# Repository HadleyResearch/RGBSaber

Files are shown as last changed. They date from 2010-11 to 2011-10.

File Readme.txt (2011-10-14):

File: README.txt
Description: Project-specific instructions and information concerning files
    located within this hierarchy and subhierarchies. In the event of
    conflicts, the lowest-level README.txt file is used for information
    regarding a file or files.

Current Location: RGBSaber/

Description:
    The RGBSaber project is an open-source electronics system for professional
lightsaber replicas. The RGBSaber electronics consist of a single channel high
power RGB LED control interface, allowing the user to implement full digital
color control over the color of the lightsaber blade.

Contents:
    Included in this repository are the source files and documentation
necessary to recreate RGBSaber. If you believe something is missing
from the project, please contact us at http://nbitwonder.com/blog/contact

Documentation:
    Documentation related to this project is included in the 'Documentation'
folder. For additional documentation and other information, please see:
    http://nbitwonder.com/blog/projects/rgbsaber

License Information:
    NBitWonder projects are released under the GNU GPL v3.0 for software,
firmware, simulations, and documentation and Creative Commons CC-BY-3.0 
for electronics and mechanical components. License copies can be found in the
file 'license.txt' in each of these top-level folders.
    NBitWonder projects may use files, software, libraries, etc. which is not
open source. These components may not be distributed within the project
repository or use a different license than that specified in license.txt. In
these cases, acquisition instructions and license exceptions are noted in a
given hierarchy's 'README.txt' file. Where conflicting, the lowest-level
'README.txt' file shall apply to a given file or files.

George Hadley
Chief Executive Officer
NBitWonder, LLC

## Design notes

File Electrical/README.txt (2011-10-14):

File: README.txt
Description: Project-specific instructions and information concerning files
    located within this hierarchy and subhierarchies. In the event of
    conflicts, the lowest-level README.txt file is used for information
    regarding a file or files.

Current Location: RGBSaber/Electrical

Components:
    The following RGBSaber components exist in this directory:
    + RGBSaber_Control: The main control board for the RGBSaber project, contains
            the microcontroller and performs all of the device functionality
    + RGBSaber_Periph1: Peripheral board for interface to RGBSaber_Control. Uses
            a sliding potentiometer, actively developed.
    + RGBSaber_Periph2: Peripheral board for interface to RGBSaber_Control. Uses
            a rotary potentiometer, not recommended.
    + Tricolor: DEPRECATED. Original version of the board containing instances of
            both the control and peripheral boards. Do not build.

Software:
    All electronic design files were created using EagleCAD v5.11 from CADSoft. 
A freeware copy of this software, as well as additional information about this 
software, can be found at http://www.cadsoftusa.com/

License:
    All electronic CAD design files contained within this hierarchy, except those
noted in the 'Exceptions' section below, are made publicly available via a 
Creative-Commons CC-BY-SA 3.0 license. For more information on the license, see 
http://creativecommons.org/licenses/by-sa/3.0/
    Additionally, a complete copy of the license text can be found in the file
'license.txt' distributed within this folder.

Exceptions:
    The following alternative licensing requirements apply to the following files:

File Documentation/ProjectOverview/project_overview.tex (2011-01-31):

% File: project_overview.tex
% Description: TeX file to generate project overview template
% Author: George Hadley
% Website: http://nbitwonder.com
% Notes:
% 1) This document is written using the LaTeX typesetting language. For a beginner's
%	guide to the LaTeX typesetting language, consult http://en.wikibooks.org/wiki/LaTeX
% 2) This document needs to be compiled using pdfLaTeX. It is not compatible with pdfTeX 
%	at the present time.
% 3) This document utilizes the nbwheader function, located in the doc_header.tex file.
%	This file is located at /path-to-documentation-templates/lbr/doc_header.tex.
% Version: 0.1
% Last Modified: 1-04-2010

\documentclass[12pt,letterpaper,onecolumn]{article}
\usepackage{graphicx}
\usepackage{float}
\usepackage{subfig}
\usepackage{tikz}
\usepackage{fancyhdr}
\usepackage{verbatim}
\usepackage{kpfonts}
\usepackage{fullpage}
\usepackage{hyperref}

%Pathway to global documentation library functions
%Modify to /path-to-documentation-templates/lbr
\newcommand{\globallbr}{../lbr}

%Page layout settings
\setlength{\voffset}{-10pt}
\setlength{\headsep}{20pt}
\setlength{\headheight}{15pt}
\setlength{\topmargin}{-20pt}

\begin{comment}
  Hyperref settings: settings for the hyperref hyperlink package.
  For a more detailed listing of available settings, consult 
  	http://en.wikibooks.org/wiki/LaTeX/Hyperlinks#Customization

  IMPORTANT: For your document, modify the pdftitle, pdfauthor, pdfsubject,
	and pdfkeywords options to tailor to your document
\end{comment}
\hypersetup{
	bookmarks=true, 					%Enable pdf bookmarks
	pdfborder={0,0,0},					%Disable borders around links
	pdftitle={Project Overview (template)},		%Name of PDF document
	pdfauthor={George Hadley},				%Author of PDF document
	pdfsubject={Embedded Electronics},		%Subject of PDF document
	pdfkeywords={diy,electronics,nbitwonder},	%Keywords for PDF document
	colorlinks={true},					%Enable colored links
	linkcolor=red,						%Internal link color
	citecolor=green,						%Citation link color
	filecolor=blue,						%File link color
	urlcolor=blue						%URL link color
}

\input{\globallbr/doc_header.tex}
\input{\globallbr/aliases.tex}

%Modify these to reflect your documentation
\newcommand{\documentationtype}{Project Overview}
\newcommand{\projectname}{RGBSaber }
\newcommand{\projectversion}{1}

%Header/Footer Definitions
\pagestyle{fancy}
\lhead{ }
\chead{ }
\rhead{\projectname  v\projectversion \documentationtype}
\lfoot{\href{http://nbitwonder.com}{http://nbitwonder.com} }
\cfoot{\thepage}
\rfoot{\copyright 2011 NBitWonder, LLC }

\begin{document}
\thispagestyle{plain}
% Insert title page or header here
\nbwheader{\documentationtype}{\projectname}{\projectversion}

%Uncomment to add Table of Contents to Project Overview
\tableofcontents
\newpage

\section[Project Description]{Project Description}
% Section: Project Description
% Description: A brief description of what your project is and what it will be used for
The RGBSaber is an open source RGB Luxeon LED driver. The driver allows for PWM modulation of an RGB
luxeon LED, allowing the color of the lightsaber blade to be adjusted to nearly any color in the RGB color spectrum. The current version of the lightsaber firmware supports 24-bit color, allowing for 16,777,216 different color combinations. The RGBSaber project, and all other NBitWonder projects, are made available under a \href{http://creativecommons.org/licenses/by-sa/3.0/}{Creative Commons 3.0 BY-SA license}.

\section[Schematics]{Schematics and Block Diagrams}
% Section: Schematics and Block Diagrams
% Description: Include any relevant high level schematics and block diagrams in this section

\section[Project Roadmap]{Project Roadmap}
% Section: Project Roadmap
% Description: Detail improvements and upgrades to be considered for future versions 
%	of the project
The RGBSaber system has considerable upgrade potential over the course of the project. A rough
project roadmap looks something like this:

\underline{\textbf{Control Board}}
\begin{enumerate}
\item\textbf{Version 1:} Basic RGBSaber system, capable of full RGB color control.
\item\textbf{Version 2:} Modular system, featuring hardware plugins for sound. Integration of
	sound with RGB color control
\item\textbf{Version 3:} Upgraded lightsaber transistor drive capabilities.
\end{enumerate}

\textbf{\underline{Peripheral Board}}
\begin{enumerate}
\item\textbf{Version 1:} Simple functional peripheral board.
\item\textbf{Version 2:} Improved peripheral board with touch interface
\end{enumerate}

\section[Project Analysis]{Project Analysis}
% Section: Project Analysis
% Description: Analysis of project compared to similar/competing projects, products, 
%	and patents. Divided into subsections (below)

\subsection[Open Source]{Open Source Project Analysis}
% Subsection: Open Source Analysis
% Description: Analysis of project compared to similar open source projects.
To date, no other known open source RGB lightsaber systems appear to exist. That said, there are a number 
of boards online that are designed to do RGB color mixing.

\subsubsection[Dangerous Prototypes]{Dangerous Prototypes USB RGB Color Changer}
Dangerous Prototypes produced a \href{http://dangerousprototypes.com/2010/01/21/usb-rgb-color-changer-build/}{USB RGB color changer} some time ago. This design was only ever in the prototype stage,
and is not in production. Additionally, the boards are far too large to fit into a lightsaber form factor and
use through-hole parts. As such, this design is not seen as a strong competitor to the RGB Lightsaber
design.

\subsubsection[Macetech]{MaceTech ShiftBrite Project}
Open source company Macetech developed and manufactures an RGB color mixing system known as the
\href{http://macetech.com/blog/?q=node/23}{ShiftBrite}. The ShiftBrite RGB system is theoretically small
enough to fit inside of a lightsaber hilt environment. However, the LEDs and the driving circuitry for the
ShiftBrite system are not bright and powerful enough to see use in a lightsaber system.

\subsection[Commercial]{Commercial Product Analysis}
% Subsection: Commercial Product Analysis
% Description: Analysis of project compared to similar commercial products
\subsubsection[Sparkfun]{Sparkfun Electronics RGB Triple Play}
In late 2010, Sparkfun electronics released the \href{http://www.sparkfun.com/products/9738}{RGB Triple Play} and an associated \href{http://www.sparkfun.com/products/9834}{driver}.
Coupled with a triple LED lens, these products certainly hit closer to the RGBSaber system. However, at the
time of this writing, these products are still too bulky to be used in a lightsaber environment, and also vastly
overpriced (costing approximately 70 dollars for the LED and drivers alone, without any control electronics).
As such, Sparkfun's products are not seen as a particular threat to the RGBSaber project.

\subsection[Plecter Labs]{Plecter Labs Crystal Focus System}
Lightsaber company Plecter Labs produces a lightsaber core system known as \href{http://www.plecterlabs.com/catalog/product_info.php?cPath=23&products_id=149}{Crystal Focus}
which is an extremely strong competitor to the RGBSaber project. The board is extremely high end, and 
features many advanced features, particularly sound and swing/clash detection.  The board is not capable
of RGB color control at the present time, and only supports a single channel. Nonetheless, the system
could be modified to support RGB color without too much effort. The system is decidedly a high-end
system at the present time (costing approximately 200 USD per board), so a slightly less featured but
cheaper board could be a prominent competitor to this system.

\subsection[Patent]{Patent Analysis}
% Subsection: Patent Analysis
% Description: Analysis of project compared to existing patents
At the present time, the RGBSaber project uses simple PWM color mixing techniques. These techniques are
trivial and well documented in the public domain, and, as such, patent analysis and infringment is not
anticipated or likely.

\section[Sources Cited]{Sources Cited}
% Section: Sources Cited
% Description: Citations for all sources used within the document.
%	Use of the IEEE citation style is highly recommended. For guidelines on using the IEEE citation style, 
%	refer to:
%	http://www.ieee.org/portal/cms_docs_iportals/iportals/publications/authors/transjnl/stylemanual.pdf

\end{document}

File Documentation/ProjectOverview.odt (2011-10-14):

Project Overview

Project: RGBSaber

Date: 10-13-2011

# 1.0. Project Description

RGBSaber is an open-source, single-channel high power LED driver. The device is capable of implementing complete digital color control on a single high-intensity LED via pulse width modulation (PWM). In this way, the color of a lightsaber blade can be changed to any color in the RGB color spectrum.

# 2.0. Project Roadmap

The following versions are considered for the RGBSaber project:

RGBSaber_Control:

- Version 1: Basic digital color control, user saveable/selectable colors, sleep mode
- Version 2: Improved connectors, modular daughterboard system, SOUND, integrated accelerometer
- Version 3: User programmability, configurable peripheral interface

RGBSaber_Periph:

- Version 1: Basic user interface
- Version 2: Capacitive touch interface

Sound Driver (supported with RGBSaber_Control v2.0 and later):

- Version 1: Basic operational model
- Version 2: Support for sound fonts, microSD card support

Transistor Driver Boards:

- 3W RGB Transistor driver
- 5W WRGB Transistor driver
- 10W WRGB Transistor driver

RGBSaber_Chassis:

- Version 1.0: Basic operational model

# 3.0. Legal Analysis

## 3.1. Regulatory Analysis and Compliance

As with other active NBitWonder projects at the time of this writing, RGBSaber has no useful defense or medical applications, does not emit appreciable radiation at any radio frequencies, and is incapable of flight. Therefore, ITAR, medical device, FCC, and FAA regulatory compliance is assumed, and regulatory issues are not expected.

## 3.2. Patent Analysis

At the time of this writing, RGBSaber utilizes extremely simple PWM color mixing techniques. These techniques are trivial and well documented in the public domain, so patent infringement and related issues are not expected.

# 4.0. Competitor Analysis

## 4.1. Open Source Project Analysis

At the time of this writing, no other known open source RGB lightsaber systems are known to exist. That said, there are a few noteworthy open source projects capable of doing RGB color mixing.

### 4.1.1. Dangerous Prototypes USB RGB Color Changer

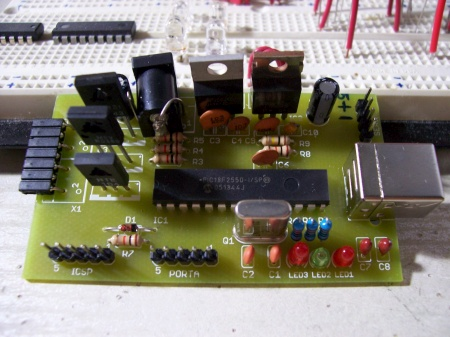
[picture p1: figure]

Fig. 1. Dangerous Prototypes USB Color Changer

Dangerous Prototypes produced a USB RGB color changer (http://dangerousprototypes.com/2010/01/21/usb-rgb-color-changer-build/) some time ago. This design was only ever in the prototype stage, was never produced, and is no longer actively developed. Additionally, the boardsare far too large to fit into a lightsaber form factor and use through-hole parts. As such, this design is not seen as a strong competitor to the RGB Lightsaber design.

### 4.1.2. MaceTech ShiftBrite Project

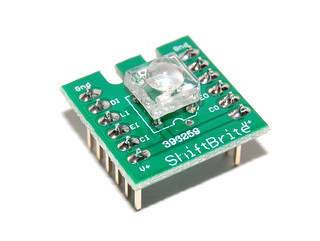
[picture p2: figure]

Fig. 2. MaceTech ShiftBrite Module

Open source company MaceTech developed and manufactures an RGB color mixing system known as the ShiftBrite (http://macetech.com/blog/?q=node/23). The ShiftBrite RGB system is theoretically small enough to fit inside of a lightsaber hilt environment. However, the LEDs and associated driving circuitry for the ShiftBrite system are not bright and powerful enough to see use in a practical lightsaber system, and no focusing optics for narrowing the ShiftBrite beam to an acceptably narrow width are known to exist.

## 4.2. Commercial Product Analysis

### 4.2.1. Sparkfun Electronics RGB Triple Play

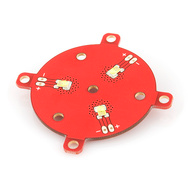
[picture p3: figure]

Fig. 3. Sparkfun RGB Triple Play

In late 2010, Sparkfun Electronics released the RGB Triple Play (http://www.sparkfun.com/products/9738) and associated drive circuitry. Coupled with a tri-LED optical lens, these products certainly hit closer to the RGBSaber system than most competitors. However, at the time of this writing, these products are still too bulky to see effective use inside of a lightsaber hilt, and are also vastly overpriced (costing approximately 70 dollars for the LED and drivers alone, without any control electronics). As such, Sparkfun's products are not seen as strong competitors to the RGBSaber project.

### 4.2.2. Plecter Labs Crystal Focus System

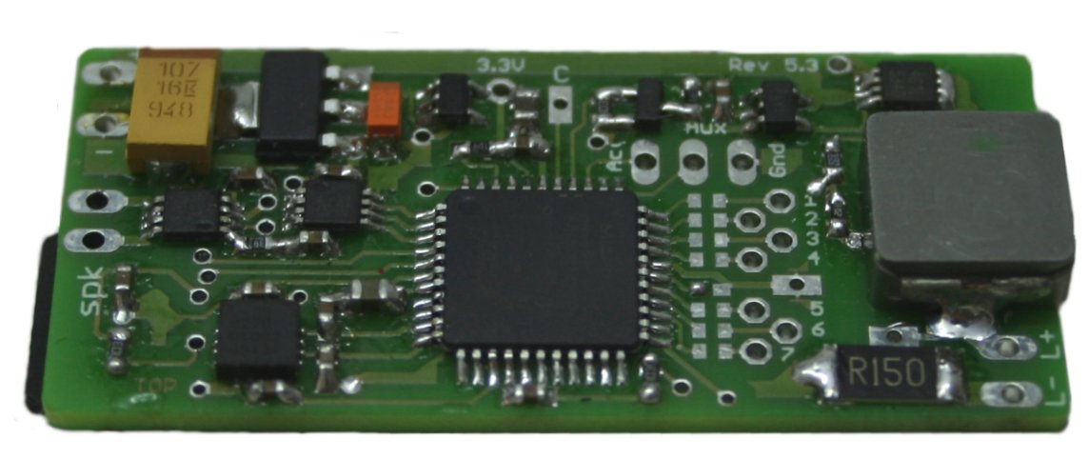
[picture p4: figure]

Fig. 4. Plecter Labs Crystal Focus System

Lightsaber company Plecter Labs produces a set of lightsaber electronics known as Crystal Focus (http://www.plecterlabs.com/catalog/product_info.php?cPath=23&products_id=149), which is seen as the primary competitor to the RGBSaber project. The board is the most advanced set of lightsaber electronics known, and includes many advanced features, such as sound and swing/clash detection. The board is not capable of RGB color control at the present time, and only supports a single channel. Nonetheless, the system could be modified to support RGB color without too much effort. The system is decidedly a high-end system at the present time (costing approximately USD 200 per board), so a slightly less featured but cheaper board could be a prominent competitor to this system.

RGBSaber Project Overview

http://nbitwonder.com 3 © 2011 NBitWonder, LLC

http://nbitwonder.com 3 ©2011 NBitWonder LLC

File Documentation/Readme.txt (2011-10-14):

File: README.txt
Description: Project-specific instructions and information concerning files
    located within this hierarchy and subhierarchies. In the event of
    conflicts, the lowest-level README.txt file is used for information
    regarding a file or files.
            
Current Location: RGBSaber/Documentation

    NBitWonder's open documentation system follows the guidelines written 
in our documentation tutorial, which can be found at:
	 http://nbitwonder.com/2010/11/09/becoming-a-better-maker-documentation/

Documents included are:
	1)  Project Overview
	2)  Project Notebook
	3)  Theory of Operation
	4)  Bill of Materials (BOM)
	5)  Construction Guide
	6)  User Manual
    
License:
	All macros and documentation templates are provided under the GNU GPL 
v3.0. A full copy of the GNU GPL v3.0 can be found at: 
    http://www.gnu.org/copyleft/gpl.html
    Additionally, a copy of the GNU GPL v3.0 should be included in the file
license.txt.
	All documentation produced by NBitWonder is the copyright of NBitWonder.
In addition, NBitWonder and the NBitWonder logo are trademarks of NBitWonder
and their use is strictly prohibited except by express written permission 
from NBitWonder, LLC.

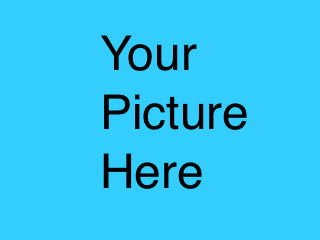
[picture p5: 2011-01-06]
Documentation/ProjectOverview/img/sample_picture.png

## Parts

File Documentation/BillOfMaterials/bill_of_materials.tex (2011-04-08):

% File: bill_of_materials.tex
% Description: TeX file to generate Bill of Materials (template)
% Author: George Hadley
% Notes:
% 1) This document is written using the LaTeX typesetting language. For a beginner's
%	guide to the LaTeX typesetting language, consult http://en.wikibooks.org/wiki/LaTeX
% 2) This document needs to be compiled using pdfLaTeX. It is not compatible with pdfTeX 
%	at the present time.
% 3) This document utilizes the nbwheader function, located in the doc_header.tex file.
%	This file is located at /path-to-documentation-templates/lbr/doc_header.tex
% Version: 0.1
% Last Modified: 1-04-2010
\documentclass[12pt,letterpaper,onecolumn,landscape]{article}
\usepackage{tikz}
\usepackage{verbatim}
\usepackage{kpfonts}
\usepackage[cm]{fullpage}
\usepackage{hyperref}

%Location of global library functions
%Change to /path-to-templates/br
\newcommand{\globallbr}{../lbr}

\begin{comment}
  Hyperref settings: settings for the hyperref hyperlink package.
  For a more detailed listing of available settings, consult 
  	http://en.wikibooks.org/wiki/LaTeX/Hyperlinks#Customization

  IMPORTANT: For your document, modify the pdftitle, pdfauthor, pdfsubject,
	and pdfkeywords options to tailor to your document
\end{comment}
\hypersetup{
	bookmarks=true, 					%Enable pdf bookmarks
	pdfborder={0,0,0},					%Disable borders around links
	pdftitle={Bill of Materials: RGBSaber v1.5},	%Name of PDF document
	pdfauthor={George Hadley},				%Author of PDF document
	pdfsubject={Documentation},			%Subject of PDF document
	pdfkeywords={diy,electronics,nbitwonder},	%Keywords for PDF document
	colorlinks={true},					%Enable colored links
	linkcolor=red,						%Internal link color
	citecolor=green,						%Citation link color
	filecolor=blue,						%File link color
	urlcolor=blue						%URL link color
}

\input{\globallbr/doc_header.tex}
\input{\globallbr/aliases.tex}

\begin{document}
	\nbwheader{Bill of Materials}{RGBSaber}{1.5}
	\\*
	\\*
	\\*
	%Include data for the components of your project. Recommended fields include description, quantity,
	%  value, package, manufacturer, mfg part #, supplier, supplier part #

	%Adjust the tab values (l/c/r = left/right/center justified, p{xcm} = constrain width to x cm (x integer)
	\noindent
	\begin{tabular}{ | p{4cm} | c | l | p{3cm} | p{4cm} | l | l | p{4cm} |}
	\hline
	\multicolumn{8}{| l |}{\textbf{RGBSaber\_Control}} \\ \hline
	\textbf{Description} & \textbf{Qty} & \textbf{Value} & \textbf{Package} & \textbf{Manufacturer} & \textbf{Manufacturer Part \#} & \textbf{Supplier} & \textbf{Supplier Part \#} \\ \hline
	%Description
	Microcontroller &
	%Quantity
	1 & 				
	%Value
	 & 		
	%Package	
	SSOP-28 & 		
	%Manufacturer
	\href{http://microchip.com}{Microchip} & 		
	%Manufacturer Part #
	\href{http://www.microchip.com/wwwproducts/Devices.aspx?dDocName=en024612}{PIC18F2221-I/SS} & 
	%Supplier
	\href{http://digikey.com}{DigiKey} &
	%Supplier Part # 
	\href{http://search.digikey.com/scripts/DkSearch/dksus.dll?Detail\&name=PIC18F2221-I/SS-ND}{PIC18F2221-I/SS-ND}
	\\ \hline
	
	%Description
	DC/DC Converter &
	%Quantity
	1 & 				
	%Value
	 & 		
	%Package	
	Through Hole & 		
	%Manufacturer
	\href{http://www.murata-ps.com/}{Murata Power Solutions} & 		
	%Manufacturer Part #
	\href{http://www.murata-ps.com/data/power/okr-t3-w12.pdf}{OKR-T/3-W12-C} & 
	%Supplier
	\href{http://digikey.com}{DigiKey} &
	%Supplier Part # 
	\href{http://search.digikey.com/scripts/DkSearch/dksus.dll?WT.z_header=search_go\&lang=en\&site=us\&keywords=okr-t\%2F3-w12\&x=0\&y=0}{811-2115-5-ND}
	\\ \hline

	%Description
	Switching Transistor &
	%Quantity
	3 & 				
	%Value
	 & 		
	%Package	
	SOT-223 & 		
	%Manufacturer
	\href{http://www.diodes.com/index.php}{Zetex Semiconductor} & 		
	%Manufacturer Part #
	\href{http://www.diodes.com/datasheets/FZTA14.pdf}{FZTA14TA} & 
	%Supplier
	\href{http://digikey.com}{DigiKey} &
	%Supplier Part # 
	\href{http://search.digikey.com/scripts/DkSearch/dksus.dll?Detail\&name=FZTA14CT-ND}{FZTA14CT-ND}
	\\ \hline

	%Description
	Feedback Resistor &
	%Quantity
	1 & 				
	%Value
	250\ohm & 		
	%Package	
	0805 & 		
	%Manufacturer
	 & 		
	%Manufacturer Part #
	 & 
	%Supplier
	 &
	%Supplier Part # 
	
	\\ \hline

	%Description
	Red BJT Base Resistor &
	%Quantity
	1 & 				
	%Value
	6.67k\ohm & 		
	%Package	
	0805 & 		
	%Manufacturer
	 & 		
	%Manufacturer Part #
	 & 
	%Supplier
	 &
	%Supplier Part # 
	
	\\ \hline

	%Description
	Green/Blue BJT Base Resistor &
	%Quantity
	2 & 				
	%Value
	3.3k\ohm & 		
	%Package	
	0805 & 		
	%Manufacturer
	 & 		
	%Manufacturer Part #
	 & 
	%Supplier
	 &
	%Supplier Part # 
	
	\\ \hline
	
	%Description
	Pull-up Resistor &
	%Quantity
	2 & 				
	%Value
	10k\ohm & 		
	%Package	
	0805 & 		
	%Manufacturer
	 & 		
	%Manufacturer Part #
	 & 
	%Supplier
	 &
	%Supplier Part # 
	
	\\ \hline
	
	%Description
	Bulk Capacitor &
	%Quantity
	1 & 				
	%Value
	100\uF & 		
	%Package	
	Electrolytic & 		
	%Manufacturer
	 & 		
	%Manufacturer Part #
	 & 
	%Supplier
	 &
	%Supplier Part # 
	
	\\ \hline	
	
	%Description
	Decoupling Capacitor &
	%Quantity
	2 & 				
	%Value
	0.01\uF & 		
	%Package	
	0805 & 		
	%Manufacturer
	 & 		
	%Manufacturer Part #
	 & 
	%Supplier
	 &
	%Supplier Part # 
	
	\\ \hline
		
	%Description
	Programming Header &
	%Quantity
	1 & 				
	%Value
	 & 		
	%Package	
	Male Header, 5 pin & 		
	%Manufacturer
	 & 		
	%Manufacturer Part #
	 & 
	%Supplier
	 &
	%Supplier Part # 
	
	\\ \hline

	%Description
	Peripheral Board Header &
	%Quantity
	1 & 				
	%Value
	 & 		
	%Package	
	JST ZH TE 7-pin & 		
	%Manufacturer
	JST America &		
	%Manufacturer Part #
	B7B-ZR-SM4-TF & 
	%Supplier
	\href{http://digikey.com}{DigiKey} & 
	%Supplier Part # 
	\href{http://search.digikey.com/scripts/DkSearch/dksus.dll?Detail\&name=455-1686-1-ND}{455-1686-1-ND}
	\\ \hline

	%Description
	Battery Header &
	%Quantity
	1 & 				
	%Value
	 & 		
	%Package	
	MTA100-2 & 		
	%Manufacturer
	Tyco Electronics & 		
	%Manufacturer Part #
	 & 
	%Supplier
	\href{http://digikey.com}{DigiKey} &
	%Supplier Part # 
	640456-2
	\\ \hline

	%Description
	Luxeon LED Header &
	%Quantity
	1 & 				
	%Value
	 & 		
	%Package	
	JST ZH SE 4-pin & 		
	%Manufacturer
	JST America &
	%Manufacturer Part #
	S4B-ZR-SM4A-TF & 
	%Supplier
	\href{http://digikey.com}{DigiKey} &
	%Supplier Part # 
	\href{http://search.digikey.com/scripts/DkSearch/dksus.dll?Detail\&name=455-1695-1-ND}{	455-1695-1-ND}
	\\ \hline

	\end{tabular}
	\newline
	\newline
	\newline
	\begin{tabular}{| p{4cm} | l | l | l | l | p{4cm} | l | p{4cm} |}
	\hline
	\multicolumn{8}{| l |}{\textbf{RGBSaber\_Periph1 (Slide Potentiometer Style)}} \\ \hline
	\textbf{Description} & \textbf{Qty} & \textbf{Value} & \textbf{Package} & \textbf{Manufacturer} & \textbf{Manufacturer Part \#} & \textbf{Supplier} & \textbf{Supplier Part \#} \\ \hline
	%description
	Slide Potentiometer & 
	%quantity 
	1 & 
	%value 
	10k\ohm & 
	%package 
	Through Hole & 
	%manufacturer 
	Alpha & 
	%mfg part number 
	RA2043F-20-10EB1-A5K & 
	%supplier 
	Mouser & 
	%supplier part number
	\href{http://www.mouser.com/ProductDetail/Alpha-Taiwan/RA2043F-20-10EB1-A5K/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\%3d}{312-219AF-5K}
	\\ \hline

	%description
	Tactile Switch SP NO & 
	%quantity 
	1 & 
	%value 
	& 
	%package 
	12mm x 12mm & 
	%manufacturer 
	Omron & 
	%mfg part number 
	B3F-4050 & 
	%suppliers 
	DigiKey & 
	%supplier part number
	SW413-ND
	\\ \hline

	%description
	9mm Dia. SwitchCap & 
	%quantity 
	1 & 
	%value 
	& 
	%package 
	& 
	%manufacturer 
	Omron & 
	%mfg part number 
	B32-1610 & 
	%suppliers 
	DigiKey & 
	%supplier part number
	SW847-ND
	\\ \hline

	%description
	RGB Indicator Common Anode & 
	%quantity 
	1 & 
	%value 
	& 
	%package 
	PLCC4 & 
	%manufacturer 
	Cree & 
	%mfg part number 
	CLV1A-FKB& 
	%suppliers 
	DigiKey & 
	%supplier part number
	CLV1AFKB-CJ1M1F1BB7R4S3CT-ND
	\\ \hline

	%Description
	Peripheral Board Header &
	%Quantity
	1 & 				
	%Value
	 & 		
	%Package	
	JST ZH TE 7-pin & 		
	%Manufacturer
	JST America &		
	%Manufacturer Part #
	B7B-ZR-SM4-TF & 
	%Supplier
	\href{http://digikey.com}{DigiKey} & 
	%Supplier Part # 
	\href{http://search.digikey.com/scripts/DkSearch/dksus.dll?Detail\&name=455-1686-1-ND}{455-1686-1-ND}
	\\ \hline

	\end{tabular}
	\newline
	\newline
	\newline
	\begin{tabular}{ | p{4cm} | l | l | l | l | p{4cm} | l | p{4cm} |}
	\hline
	\multicolumn{8}{| l |}{\textbf{RGBSaber\_Periph2 (Rotary Potentiometer Style)}} \\ \hline
	\textbf{Description} & \textbf{Qty} & \textbf{Value} & \textbf{Package} & \textbf{Manufacturer} & \textbf{Manufacturer Part \#} & \textbf{Supplier} & \textbf{Supplier Part \#} \\ \hline
	%description
	Rotary Potentiometer & 
	%quantity 
	1 & 
	%value 
	10k\ohm & 
	%package 
	Through Hole & 
	%manufacturer 
	Bourns & 
	%mfg part number 
	& 
	%supplier 
	& 
	%supplier part number
	
	\\ \hline

	%description
	Tactile Switch SP NO & 
	%quantity 
	1 & 
	%value 
	& 
	%package 
	6mm x 6mm & 
	%manufacturer 
	& 
	%mfg part number 
	& 
	%suppliers 
	& 
	%supplier part number
	
	\\ \hline

	%description
	RGB Indicator Common Anode & 
	%quantity 
	1 & 
	%value 
	& 
	%package 
	Discrete 5mm & 
	%manufacturer 
	& 
	%mfg part number 
	& 
	%suppliers 
	& 
	%supplier part number
	
	\\ \hline

	%description
	Peripheral Board Header & 
	%quantity 
	1 & 
	%value 
	& 
	%package 
	MTA100-7 & 
	%manufacturer 
	Tyco Electronics & 
	%mfg part number 
	& 
	%suppliers 
	& 
	%supplier part number
	640456-7
	\\ \hline

	\end{tabular}
	\newline
	\newline
	\newline
	\begin{tabular}{ | p{4cm} | c | l | l | p{4cm} | l | l | l |}
	\hline
	\multicolumn{8}{| l |}{\textbf{Other}} \\ \hline
	\textbf{Description} & \textbf{Qty} & \textbf{Value} & \textbf{Package} & \textbf{Manufacturer} & \textbf{Manufacturer Part \#} & \textbf{Supplier} & \textbf{Supplier Part \#} \\ \hline
	%description 
	Ribbon Cable 28 AWG & 
	%quantity 	
	1 ft & 
	%value 	
	& 
	%package 
	& 
	%manufacturer 
	& 
	%mfg part number 
	& 
	%supplier 
	& 
	%supplier part number
	\\ \hline

	%description 
	Peripheral Cable Plug & 
	%quantity 	
	2 & 
	%value 	
	& 
	%package 
	JST ZH 7-pin & 
	%manufacturer 
	JST America & 
	%mfg part number 
	ZHR-7& 
	%supplier 
	DigiKey & 
	%supplier part number
	455-1200-ND
	\\ \hline

	%description 
	Battery Pack Plug & 
	%quantity 	
	1 & 
	%value 	
	& 
	%package 
	MTA100-2 & 
	%manufacturer 
	Tyco Electronics & 
	%mfg part number 
	& 
	%supplier 
	DigiKey & 
	%supplier part number
	3-640621-2 
	\\ \hline

	%description 
	Luxeon LED Plug & 
	%quantity 	
	1 & 
	%value 	
	& 
	%package 
	JST ZH 4-pin & 
	%manufacturer 
	JST America & 
	%mfg part number 
	ZHR-4& 
	%supplier 
	DigiKey & 
	%supplier part number
	455-1202-ND
	\\ \hline

	%description 
	7.4V Li-Ion Battery Pack & 
	%quantity 	
	& 
	%value 	
	& 
	%package 
	& 
	%manufacturer 
	& 
	%mfg part number 
	& 
	%supplier 
	& 
	%supplier part number
	\\ \hline

	%description 
	2.1mm DC Barrel Jack & 
	%quantity 	
	& 
	%value 	
	& 
	%package 
	& 
	%manufacturer 
	& 
	%mfg part number 
	& 
	%supplier 
	& 
	%supplier part number
	\\ \hline

	%description 
	SPST Power Switch & 
	%quantity
	1 & 
	%value 	
	& 
	%package 
	& 
	%manufacturer 
	& 
	%mfg part number 
	& 
	%supplier 
	& 
	%supplier part number
	\\ \hline

	%description 
	Luxeon LED: Red & 
	%quantity 	
	1 & 
	%value 	
	& 
	%package 
	3mm x 4.5mm & 
	%manufacturer 
	Phillips & 
	%mfg part number 
	& 
	%supplier 
	LuxeonStar & 
	%supplier part number
	LXM2-PD01-0050
	\\ \hline

	%description 
	Luxeon LED: Green & 
	%quantity 	
	1 & 
	%value 	
	& 
	%package 
	3mm x 4.5mm & 
	%manufacturer 
	Phillips & 
	%mfg part number 
	& 
	%supplier 
	LuxeonStar & 
	%supplier part number
	LXML-PM01-0070
	\\ \hline

	%description 
	Luxeon LED: Royal Blue & 
	%quantity 	
	1 & 
	%value 	
	& 
	%package 
	3mm x 4.5mm& 
	%manufacturer 
	Phillips & 
	%mfg part number 
	& 
	%supplier 
	DigiKey & 
	%supplier part number
	LXML-PR01-0350
	\\ \hline

	%description 
	MCPCB LED Tri-Star Base & 
	%quantity 	
	1 & 
	%value 	
	& 
	%package 
	& 
	%manufacturer 
	LuxeonStar & 
	%mfg part number 
	& 
	%supplier 
	LuxeonStar & 
	%supplier part number
	LXB-RT20B
	\\ \hline

	%description 
	Carclo Tri-Lens 22deg & 
	%quantity 	
	1 & 
	%value 	
	& 
	%package 
	& 
	%manufacturer 
	Carclo Performance Plastics & 
	%mfg part number 
	& 
	%supplier 
	LuxeonStar & 
	%supplier part number
	10506
	\\ \hline

	\end{tabular}
\end{document}

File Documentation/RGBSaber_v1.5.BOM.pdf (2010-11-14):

Bill of Materials

Date: 10/20/2010
Project: RGBSaber
Version: v1.5

RGBSaber_Control
Description | Part Number | Package | Qty | Manufacturer
Microcontroller | PIC18F2221 | SSOP-28 | 1 | Microchip
DC/DC Converter | OKR-T/3-W12 | Through Hole | 1 | Murata Power Solutions
Switching Transistor | FZTA14 | SOT223 | 3 | Zetex
250Ω Resistor | MC1206S4F2550T5E | 1206 | 1 | Multicomp
3.3kΩ Resistor | ERJ-8GEYJ332V | 1206 | 1 | Panasonic ECG
6.67kΩ Resistor | ERJ-8ENF6651V | 1206 | 2 | Panasonic ECG
10kΩ Resistor | ERJ-8GEYJ103V | 1206 | 2 | Panasonic ECG
100uF Bulk Capacitor | ECA-1EM101 | Electrolytic | 1 | Panasonic ECG
0.1uF Capacitor | GRM188F51E104ZA01D | 0805 | 2 | Murata Electronics
0.01uF Capacitor | GRM216R71H103KA01D | 0806 | 3 | Murata Electronics
Programming Header | 77315-424-05LF | | 1 | FCI
Peripheral Board Header | 640456-7 | MTA100 | 1 | Tyco Electronics/AMP
Battery Header | 640456-2 | MTA100 | 1 | Tyco Electronics/AMP
RGB LED Header | 640456-4 | MTA100 | 1 | Tyco Electronics/AMP

RGBSaber_Periph1 (Slide Potentiometer Style)
Description | Part Number | Package | Qty | Manufacturer
Slide Potentiometer | 56P5194 | Discrete | 1 | Bourns
Tactile Switch | TL1105LF160Q | Discrete | 1 | E-Switch
RGB Indicator LED CA | 17137 OP | Discrete | 1 | Ming
Board Header | 640456-7 | MTA100 | 1 | Tyco Electronics/AMP

RGBSaber_Periph2 (Rotary Potentiometer Style)
Description | Part Number | Package | Qty | Manufacturer
Rotary Potentiometer | 3310Y-001-103L | Discrete | 1 | Bourns
Tactile Switch | TL1105LF160Q | Discrete | 1 | E-Switch
RGB Indicator LED CA | 17137 OP | Discrete | 1 | Ming
Board Header | 640456-7 | MTA100 | 1 | Tyco Electronics/AMP

Other
Description | Part Number | Package | Qty | Manufacturer
Ribbon Cable
Peripheral Cable Plug | 3-640443-7 | MTA100 | 1 | Tyco Electronics/AMP
Battery Pack Plug | 3-640621-2 | MTA100 | 1 | Tyco Electronics/AMP
RGB LED Plug | 3-640621-4 | MTA100 | 1 | Tyco Electronics/AMP

7.4 Li-Ion Battery Pack | 1
2.1mm DC Barrel Socket | 1
SPST Power Switch | 1
RGB Luxeon LED | 1

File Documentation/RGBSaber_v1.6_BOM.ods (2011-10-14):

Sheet: BOM
 |  |  |  |  | Document: | Bill of Materials
 |  |  |  |  | Last Modified: | 10/13/2011
 |  |  |  |  | Project: | RGBSaber
 |  |  |  |  | Project Version: | 1.6
RGBSaber_Control
Description | ID | Qty | Value | Package | Manufacturer | Mfg. Part # | Supplier | Supplier Part #
Microcontroller |  | 1 |  | SSOP28 | Microchip | PIC18F2221-I/SS | DigiKey | PIC18F2221-I/SSND
DC/DC Converter |  | 1 |  | SIP 1x5 2mm | Murata Power | OKR-T/3-W12-C | DigiKey | 811-2115-5-ND
Switching Transistor |  | 3 |  | SOT-223 | Diodes, Inc. | FZTA14TA | DigiKey | FZTA14CT-ND
Feedback Resistor |  | 1 | 250 | 0805
Red BJT Base Resistor |  | 1 | 6.67k | 0805
Green/Blue Base Resistor |  | 2 | 3.3k | 0805
Pull-up Resistor |  | 2 | 10k | 0805
Bulk Capacitor |  | 1 | 100uF | PTH
Decoupling Capacitor |  | 2 | 0.01uF | 0805
Programming Header |  | 1 |  | 1x5 2.54mm
Peripheral Board Header |  | 1 |  | JST ZH TE 7-pin | JST America | B7B-ZR-SM4-TF | DigiKey | 455-1686-1-ND
Battery Header |  | 1 |  | MTA100-2 | Tyco Electronics |  | DigiKey | 640456-2
Luxeon LED Header |  | 1 |  | JST ZH SE 4-pin | JST America | S4B-ZR-SM4A-TF | DigiKey | 455-1695-1-ND
RGBSaber_Periph1 (Slide Potentiometer Style)
Description | ID | Qty | Value | Package | Manufacturer | Mfg. Part # | Supplier | Supplier Part #
Slide Potentiometer |  | 1 | 10k | PTH | Alpha | RA2043F-20-10EB1-A5K | Mouser | 312-219AF-5K
Tactile Switch SP NO |  | 1 |  | 12x12mm | Omron | B3F-4050 | DigiKey | SW413-ND
9mm Dia. Switch Cap. |  | 1 |  |  | Omron | B32-1610 | DigiKey | SW847-ND
RGB Common Anode LED |  | 1 |  | PLCC4 | Cree | CLV1A-FKB | DigiKey | CLV1AFKBCJ1M1F1BB7R4S3CTND
Peripheral Board Header |  | 1 |  | JST ZH TE 7-pin | JST America | B7B-ZR-SM4-TF | DigiKey | 455-1686-1-ND
RGBSaber_Periph2 (Rotary Potentiometer Style)
Description | ID | Qty | Value | Package | Manufacturer | Mfg. Part # | Supplier | Supplier Part #
Rotary Potentiometer |  | 1 | 10k | PTH | Bourns
Tactile Switch SP NO |  | 1 |  | 6x6mm
RGB Common Anode LED |  | 1 |  | Discrete 5mm
Peripheral Board Header |  | 1 |  | MTA100-7 | Tyco Electronics |  | DigiKey | 640456-7
Other
Description | ID | Qty | Value | Package | Manufacturer | Mfg. Part # | Supplier | Supplier Part #
Ribbon Cable 28 AWG |  | 1 ft
Peripheral Cable Plug |  | 2 |  | JST ZH 7-pin | JST America | ZHR-7 | DigiKey
Battery Pack Plug |  | 1 |  | MTA100-2 | Tyco Electronics |  | DigiKey
Luxeon LED Plug |  | 1 |  | JST ZH 4-pin | JST America | ZHR-4 | DigiKey
7.4V Li-Ion Battery Pack |  | 1
2.1mm DC Barrel Jack |  | 1
SPST Power Switch |  | 1
Luxeon Rebel LED: Red |  | 1 |  | 3x4.5mm | Phillips |  | LuxeonStar | LXM2-PD01-0050
Luxeon Rebel LED: Green |  | 1 |  | 3x4.5mm | Phillips |  | LuxeonStar | LXML-PM01-0070
Luxeon Rebel LED: Blue |  | 1 |  | 3x4.5mm | Phillips |  | LuxeonStar | LXML-PR01-0350
MCPCB LED Tri-Star Base |  | 1 |  |  | LuxeonStar |  | LuxeonStar | LXB-RT20B
Carclo Tri-LED Lens 22deg |  | 1 |  |  | Carclo Plastics |  | LuxeonStar | 10506

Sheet: Config
AtomicBOM Configuration Data:
Parameter | Description | Default Value | Value
maxResults | Maximum number of results to display for part searches (integer) | 5 | 5
maxSuppliers | Maximum number of suppliers to display for part searches (integer) | 5 | 5
suppliersInclude | List of suppliers to include in search results (comma separated list)
suppliersExclude | List of suppliers to exclude in search results (comma separated list)
filterROHS | Return only ROHS compliant parts (1: yes, 0: no) | 0 | 0
cacheParts | Cache part data for more efficient future searches (1: yes, 0: no) | 0 | 0
getDatasheetURLs | Return/embed datasheet URLs, if they exist (1: yes, 0: no) | 1 | 1
getSupplierURLs | Return/embed supplier URLs, if they exist (1: yes, 0: no) | 1 | 1
logging | Enable log information for macro (1: yes, 0: no) | 1 | 1
logFile | Filepath to program log file (string)
logLevel | Number corresponding to logging intensity (0-4) | 2 | 2
bundleParts | Bundle parts from single supplier (reduce shipping costs) | 0 | 0
minBundle | Minimum order (dollar value) for part bundling
versionCheck | Check for new versions of AtomicBOM macro suite | 0 | 0
versionURL | AtomicBOM updated version URL
bomVer | Current version of AtomicBOM macro | 0 | 0

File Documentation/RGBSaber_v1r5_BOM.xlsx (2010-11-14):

Bill of Materials
Date: 10/20/2010
Project: RGBSaber
Version: v1.5
RGBSaber_Control
Description | Part Number | Package | Qty | Manufacturer | Link
Microcontroller | PIC18F2221 | SSOP-28 | 1 | Microchip | Link (http://www.microchip.com/wwwproducts/Devices.aspx?dDocName=en024612)
DC/DC Converter | OKR-T/3-W12 | Through Hole | 1 | Murata Power Solutions | Link (http://search.digikey.com/scripts/DkSearch/dksus.dll?lang=en&site=US&WT.z_homepage_link=hp_go_button&x=0&y=0)
Switching Transistor | FZTA14 | SOT223 | 3 | Zetex | Link
250Ω Resistor | MC1206S4F2550T5E | 1206 | 1 | Multicomp | Link
3.3kΩ Resistor | ERJ-8GEYJ332V | 1206 | 1 | Panasonic ECG | Link
6.67kΩ Resistor | ERJ-8ENF6651V | 1206 | 2 | Panasonic ECG | Link
10kΩ Resistor | ERJ-8GEYJ103V | 1206 | 2 | Panasonic ECG | Link
100uF Bulk Capacitor | ECA-1EM101 | Electrolytic | 1 | Panasonic ECG | Link
0.1uF Capacitor | GRM188F51E104ZA01D | 0805 | 2 | Murata Electronics | Link
0.01uF Capacitor | GRM216R71H103KA01D | 0806 | 3 | Murata Electronics | Link
Programming Header | 77315-424-05LF |  | 1 | FCI | Link
Peripheral Board Header | 640456-7 | MTA100 | 1 | Tyco Electronics/AMP | Link
Battery Header | 640456-2 | MTA100 | 1 | Tyco Electronics/AMP | Link
RGB LED Header | 640456-4 | MTA100 | 1 | Tyco Electronics/AMP | Link
RGBSaber_Periph1 (Slide Potentiometer Style)
Description | Part Number | Package | Qty | Manufacturer | Link
Slide Potentiometer | 56P5194 | Discrete | 1 | Bourns | Link
Tactile Switch | TL1105LF160Q | Discrete | 1 | E-Switch | Link
RGB Indicator LED CA | 17137 OP | Discrete | 1 | Ming | Link
Board Header | 640456-7 | MTA100 | 1 | Tyco Electronics/AMP | Link
RGBSaber_Periph2 (Rotary Potentiometer Style)
Description | Part Number | Package | Qty | Manufacturer | Link
Rotary Potentiometer | 3310Y-001-103L | Discrete | 1 | Bourns | Link
Tactile Switch | TL1105LF160Q | Discrete | 1 | E-Switch | Link
RGB Indicator LED CA | 17137 OP | Discrete | 1 | Ming | Link
Board Header | 640456-7 | MTA100 | 1 | Tyco Electronics/AMP | Link
Other
Description | Part Number | Package | Qty | Manufacturer | Link
Ribbon Cable
Peripheral Cable Plug | 3-640443-7 | MTA100 | 1 | Tyco Electronics/AMP | Link
Battery Pack Plug | 3-640621-2 | MTA100 | 1 | Tyco Electronics/AMP | Link
RGB LED Plug | 3-640621-4 | MTA100 | 1 | Tyco Electronics/AMP | Link
7.4 Li-Ion Battery Pack |  |  | 1
2.1mm DC Barrel Socket |  |  | 1
SPST Power Switch |  |  | 1
RGB Luxeon LED |  |  | 1

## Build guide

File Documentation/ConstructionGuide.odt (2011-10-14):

Construction Guide

Project: ProjectName

Date: ManualDate

ProjectName Construction Guide

http://nbitwonder.com 2 ©2011 NBitWonder LLC

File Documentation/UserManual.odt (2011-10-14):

User Manual

Project: ProjectName

Date: ManualDate

# 1.0. Introduction

Briefly describe the product, it's purpose, it's function. Describe the items that should have come with the product (all boards, SD card, batteries, etc.). Describe any complementary items that can be used with the product (accessories, etc.)

# 2.0. Usage Information

Information related to the usage of the project. Describe any assembly information needed for this project (if the project doesn't come fully assembled). Detail navigation through any and all software menus. Describe important basic procedures, such as changing the batteries or replacing the SD card.

# 3.0. Safety Information

Their may be some relevant safety issues for your project that users should know. Some are very trivial (choking hazard, keep away from water). Some may be special information relevant to your product (example: if your product contains a laser, a warning about not pointing it in a person's eyes is probably reasonable)

# 4.0. Care Information

Information about maintaining a product. This section might contain information about replacing the batteries, or conditions for storage (ex. store in a cool, dry place). Additionally, any disposal or recycling instructions should be included here.

# 5.0. Support Information

Technical support and other relevant information. This section might include frequently asked questions or common troubleshooting steps. Also, add any contact information (email, website, phone) for additional support information for your product.

# 6.0. Legal Information

Some types of products and equipment may have important legal considerations related to their use (example: for recording equipment, recording private conversations as a third-party is illegal in many states). Provide the user with any important legal information to help keep them, and your company, safe from lawsuits. Additionally, consider adding licensing information (even if you're using an open license) in this section. If your product is to have a warranty, this section is where you'll want to include that.

http://nbitwonder.com 2 [Insert Copyright etc. here]

http://nbitwonder.com 2 ©2011 NBitWonder LLC

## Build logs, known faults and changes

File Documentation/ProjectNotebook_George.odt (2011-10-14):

Project Notebook

Project: RGBSaber

Author: George Hadley

This past weekend I once again attempted to construct the RGB Lightsaber, using the chassis I had ordered from the Custom Saber Shop. Unfortunately, an unknown internal short occurred within this lightsaber, destroying the control board. This and other problems have forced me to redesign the RGB driver board, resulting in RGBSaber v1.5. A list of changes to be made in v1.5 include the following:

Entry: 001 Time: 8/22/2010 19:24 UTC Version: 1.4 Title: v1.5 Redesign

1. Change power source from 6-AA NiMH batteries to 2-cell 7.4V Li-Ion pack. In making this change, undervoltage protection must be included in Li-Ion pack to prevent damage to the batteries.
2. Flip power converter unit to top-side of the board. The lithium ion protection circuitry may be placed on the bottom of the board.
3. Move RGB led connector from top edge of board to the right side of the board to ease connection issues.
4. Use connectors for all interfaces, to maximize reuse and increase reliability (solder makes for poor electrical connections).
5. Minimize wiring inside of lightsaber chassis. Try to limit wire lengths to 3 inches or less.

Today I am performing redesign work on the RGB Lightsaber, designing and laying out RGBSaber v1.5. In order to get the saber up and running, reliable connectors are required for the design. As such, today’s entry details the search for good connectors to use on the RGB Lightsaber project.

Entry: 002 Time: 8/26/2010 19:26 UTC Version: 1.5 Title: v1.5 Connectors

To begin the search, I went to Molex (http://www.molex.com/) and began looking at the connector options they had, with hopes of getting free samples of some of the connectors. Promising connectors included the PicoBlade connectors for the peripheral board connection. Unfortunately, after additional searching, it was determined that the crimping tools needed for the PicoBlade connectors were prohibitively expensive (hundreds of dollars) and cable subassemblies did not appear to be available.

Following yesterday’s connector search, I continued the search for reliable, feasible connectors to use for the RGBSaber project. Leaving Molex and looking for connector possibilities over at Tyco Electronics (http://tycoelectronics.com/), I found some additional promising possibilities. Particularly promising were the Micro-MaTch (http://www.tycoelectronics.com/catalog/feat/en/c/11398?BML=10576,17560,23645,17587) and MTA100 (http://www.tycoelectronics.com/catalog/feat/en/s/23478?BML=10576,17560,23645,17587) connectors. More promising still, a crimping tool was available for these connectors at a very reasonable price of 18 dollars.

Entry: 003 Time: 8/27/2010 19:27 UTC Version: 1.5 Title: v1.5 Undervoltage Protection

Having found a reasonable connector option for the board, I proceeded to investigate undervoltage protection options for the lightsaber power circuitry. In order to meet acceptable size requirements, v1.5 of the RGBSaber circuitry is to be powered by a 2-cell 7.4V Li-Ion battery pack. To prevent damage to the Li-Ion pack, a simple analog circuit will be designed to kill power to the circuit in the event that the battery pack voltage drops below 5.6V (signifying an undervoltage condition).

Research continued on the Li-Ion undervoltage protection circuit. Comparator circuits were investigated for their use within the RGBSaber control circuit. I was hoping to utilize a comparator with an integrated voltage reference, however, these were shown to be prohibitively expensive. Therefore, a general purpose comparator will be used, with a zener diode providing a reliable onboard voltage reference.

Entry: 004 Time: 9/01/2010 19:51 UTC Version: 1.5 Title: v1.5 Undervoltage Protection 2

Further research on the lithium ion battery packs revealed that lithium ion packs can be purchased which incorporate integrated circuitry protection, negating the need for onboard circuitry protection on the lightsaber board. After some research, this battery pack (http://www.batteryjunction.com/tenergy-18650-2200-pk.html), found at BatteryJunction (http://www.batteryjunction.com/), showed particular promise for use in the RGB lightsaber.

Entry: 005 Time: 9/01/2010 19:52 UTC Version: 1.5 Title: v1.5 Battery Pack Research

Given that the new Li-Ion pack incorporates integrated protection circuitry, no schematic redesigns appear to be necessary to implement v1.5. The battery pack and associated Li- Ion charger (http://www.batteryjunction.com/unsmchforlib.html) were ordered for use in the RGB Lightsaber design.

Having some free time to spare, I redesigned the layout of the RGB lightsaber, creating the RGBSaber v1.5 board. Changes made to the new version of the PCB include rotating the onboard primary decoupling capacitor, flipping the voltage regulator to the top side of the board, and moving the LED connector to the front of the board for easier access to the LED within the lightsaber chassis. I ran the design through Eagle’s built in DRC, but will submit it to peer review by one or more ECE friends before ordering.

Entry: 006 Time: 9/03/2010 19:55 UTC Version: 1.5 Title: v1.5 Redesign Complete

Today I ordered parts to construct RGBSaber v1.5. Additionally, I added some finishing touches to the RGBSaber v1.5 PCB, such as fixing some ground plane isolation issues and tenting all the vias on the board, which had been suggested by Ben. With those changes implemented, I panelized the control board and an older version of the peripheral board, and ordered these boards from Advanced Circuits (http://www.4pcb.com/).

Entry: 007 Time: 9/05/2010 19:56 UTC Version: 1.5 Title: Parts/PCB Ordering

I finally opened the parts I had ordered from DigiKey from DigiKey only to discover that the Li-Ion battery pack I had ordered was ever so slightly too wide to fit inside of the nice MHS main body tube I had ordered from the Custom Saber Shop. As luck would have it, however, the Li-Ion pack was just barely able to fit inside the 1.5” sink tube that I had been using for the original RGB lightsaber chassis. I ordered a pair of sink tube to MHS adapters from the Custom Saber Shop to try to utilize this quality. After doing so, however, I discovered that the sink tube fits over the outside of the MHS tube. Therefore, the current plan is to use the MHS hilt as the core of the saver build and then extend the hilt as needed with some 12” sink tube.

Entry: 008 Time: 9/11/2010 19:57 UTC Version: 1.5 Title: Chassis Plans

RGBSaber v1.5 PCBs arrived today, and, in what has become troublingly predictable, the v1.5 prototype contained several imperfections, and, among other things, does not function properly. The cause of this is at this time unknown. v1.6 will doubtlessly be created, but, in the meantime, here is a list of issues and mistakes made in building v1.5:

Entry: 009 Time: 9/17/2010 19:59 UTC Version: 1.5 Title: v1.5 Failure

1. Tyco MTA100 connectors obscure the silkscreens on the busses they are associated with. Solution: Add silkscreens to the bottom of the board.
2. Switching transistors have very thin wire supplying power from the microcontroller. Solution: Reroute board to supply direct power mains to switching transistors, add power line audits to PCB design check.
3. Battery header, program header, and DC/DC converter are spaced too close together. Solution: no solution proposed at present time.
4. Standoff hole near batter header is partially obscured by battery header. Solution: Add spacing around left side standoff holes
5. Resistors Under DC/DC converter need to be centered to provide more balance
6. Resistors/Capacitors should be standardized to smaller part size (0805 or 0603)
7. Consider relocating resistors beneath DC/DC converter to underside of board

In spite of the unfortunate outcome of the RGBSaber v1.5 board, a few good things did

come of it. In particular, I now have the tools and materials to implement connectors

on my board, which is so useful I think I will mandate it for all multi-board projects.

Additionally, the creation of RGBSaber v1.5 facilitated the development of the Microsoft

Word project notebook template, which has been quite helpful in documenting work on

the RGB lightsaber project.

It’s been quite awhile since I have documented the state of the RGBSaber project, largely because there hasn’t been much to report in the way of actual development work of the circuit boards. After troubleshooting the first RGBSaber board I constructed a second board, fixing the power wiring to the transistors problem (outlined above). Upon doing so, the RGBSaber v1.5 board worked correctly and demonstrated all current functionality. Thereafter, I constructed the first fully operational RGBSaber model, and have been working slowly on documenting the complete build process for RGBSaber v1.5.

Entry: 010 Time: 10/11/2010 20:09 UTC Version: 1.5 Title: Build Progress Update

I took the RGBSaber over to Eric Lauber’s house to demonstrate its functionality today. It worked for a little while, and then broke mysteriously. After careful diagnostic work of the RGBSaber, it has been determined that the control electronics of the RGBSaber were not the source of the failure, but rather some as-of-yet unidentified issue with the device power supply. Taking a voltage reading of the battery voltage through the charge port jack yielded very low voltage values ( 0.125V) and a resistance measurement of the power jack suggested that no internal shorts were occurring between power and ground. In light of this information, the only current suspect for the RGBSaber failure is a broken or faulty wire within the RGBSaber. More diagnostic work will be done on the saber to try to determine the source of the problem.

Entry: 011 Time: 10/11/2010 20:12 UTC Version: 1.5 Title: Power Electronics Failure

In the meantime, however, RGBSaber v1.5 is our of the hilt, providing me with an opportunity to look into streamlining and developing RGBSaber v1.6, planned to be the last revision of RGBSaber v1, which will feature many improvements to the RGBSaber control electronics. Among these are:

RGBSaber Control:

1. Use of SMD decoupling capacitor
2. Move to 0805 resistors and capacitors
3. More powerful drive transistors
4. Better DC/DC converter placement (resistors currently under DC/DC Converter)
5. Improved peripheral electronics interface to allow more durable discrete elements to be used with RGBSaber instead of just peripheral board.
6. Move to JST or other small connectors instead of MTA-100 connectors
7. Interface for second pushbutton

RGBSaber Periph:

1. Use of SMD RGB indicator LED
2. JST or other smaller connector to replace MTA100 connector
3. Surface mount connector
4. Revert to 2 pushbutton system
5. More durable pushbuttons

I spent some more time working on the RGBSaber project today. RGBSaber Control is now at version 1.6 proper, with a silkscreened NBitWonder logo having been applied to the PCB in addition to some other fixes mentioned above. Additionally, Microchip finally released C18 (still in Beta) for their MPLABX platform, meaning I can finally do firmware development on Mac OSX. As such, I have begun the code port for RGBSaber in C.

Entry: 012 Time: 12/09/2010 20:15 UTC Version: 1.6 Title: Firmware v1.6, C Port

I spent some time today working on the C device code for the RGBSaber project, and, I can say with pride that an initial port of the core functionality has been completed. It builds successfully, although a successful embedded test has not occurred at the present time.

Entry: 013 Time: 12/15/2010 20:16 UTC Version: 1.6 Title: Firmware v2.0 C Code Completed

Activity has been somewhat dormant on the RGBSaber for the past couple of months. With improvements for RGBSaber v1.6 planned, it was time to find parts that could be used to meet those improvements (see entry 11 for a refresher on RGBSaber v1.6 improvements). Details on what was done for meeting the improvements are shown below:

Entry: 014 Time: 3/26/2011 20:17 UTC Version: 1.6 Title: Sample Parts and PCB Layout v1.6

1. Use of SMD Decoupling Capacitor: The through-hole decoupling capacitors used in RGBSaber v1.5 and earlier were adequate, but took up lots of space. A smaller SMD capacitor would help save space on the RGBSaber board, where space is critical. I did some searching, and found a minimal SMD capacitor from Panasonic. The cap is quite small, and cheap, and only requires an estimated 40% of the volume needed by the previous through-hole electrolytic. As a small but largely unimportant consequence, the cap has a voltage rating of 16V instead of the overkill 50V rating of the through-hole electrolytic, but 16V is above the maximum voltage rating for the onboard regulator, so this is not seen as a problem.
2. Move to 0805 resistors and capacitors: Trivial. Done.
3. More powerful drive transistors: RGBSaber v1.5 and earlier utilized the FZTA14 NPN Darlington Transistors (http://search.digikey.com/scripts/DkSearch/dksus.dll?Detail&name=FZTA14CT-ND) from Zetex. This is a 2W part with a maximum continuous collector current of 1A. When searching DigiKey, I found a similar part, the FZT7053 (http://search.digikey.com/scripts/DkSearch/dksus.dll?Detail&name=FZT7053TACT-ND), that might serve as a suitable replacement for the FZTA14. It is pin compatible with the FZTA14, but boasts a higher collector current rating of 1.5A and an overall power dissipation of 6.25W (instead of 2), while only costing 9 cents more than the FZTA14. The perceived downside to this part is that it has some differing electrical characteristics (base-emitter voltage, gain, etc.), that may make it more involved than a simple drop-in replacement for the FZTA14. From a layout perspective, the chips have identical footprints, so revisions to the board layout are not needed at the present time.
4. Better DC/DC converter placement: To be handled in PCB layout (next).
5. Improved peripheral electronics interface to allow more durable discrete elements to be used with RGBSaber instead of just peripheral board: This improvement was considered and evaluated, but ultimately discarded in favor of more durable tactile switches (discussed below)
6. Move to JST or other small connectors instead of MTA100 connectors: This was one of the most important criterion for RGBSaber v1.6. In the build of RGBSaber v1.5, it was discovered that the connectors occupied too much space, particular in terms of height, to fit effectively inside of the lightsaber hilt. Before moving to smaller connectors, however, a crimping solution for the connectors needed to be found. As luck would have it, a versatile but reasonably priced tool for JST connectors was found over at Sparkfun Electronics (http://www.sparkfun.com/products/10219). With this tool, I was able to crimp a sample JST ZH series connector (http://www.jst-mfg.com/product/pdf/eng/eZH.pdf) and determine their feasibility for the RGBSaber project. These connectors are much smaller than the Tyco MTA-100 connectors, and rated for a current of 1A. Qualitative analysis shows that these connectors occupy an estimated 50% of the height and 60% of the width of the equivalent MTA-100 connector, and the physical connection is sound (there shouldn’t be any problems with the connector becoming disconnected during lightsaber use). The 1A rating is too low for use in the battery connector, however, so a right-angle MTA100 connector, or possibly some sort of screw terminals, will be used for the power connection.
7. Interface for second pushbutton: More thought needs to be put into whether or not to include a second pushbutton and interface for RGBSaber v1.6. The current thinking is to omit this second pushbutton for now until additional features are added to the RGBSaber system.
8. Use of SMD RGB indicator LED: RGBSaber v1.5 and earlier utilized a 5mm RGB indicator LED. While effective, this LED was somewhat costly, and had leads that protruded from the board, a potential hazard for short circuits. As such, an RGB SMD indicator was found in a PLCC-4 package (http://search.digikey.com/scripts/DkSearch/dksus.dll?Detail&name=CLV1A-FKB-CJ1M1F1BB7R4S3CT-ND) from Cree.
9. More durable pushbuttons: My initial approach to this problem was to attempt to replace the tactile switches used in RGBSaber v1.5 and earlier with pushbutton switches. None could be found with appropriate characteristics and cost, so this approach was abandoned. Instead, a pushbutton and cap system approach was adopted. That way, any mechanical strain applied perpendicularly to the switch shaft would be handled by the interface with the tactile switch cap, and not necessarily destroy the tactile switch itself. After a bit of searching on DigiKey, I found a suitable tactile switch (http://search.digikey.com/scripts/DkSearch/dksus.dll?Detail&name=SW801-ND) from the Omron B3F series and a matching switch cap (http://search.digikey.com/scripts/DkSearch/dksus.dll?vendor=0&keywords=SW847-ND). These should be very effective for use in RGBSaber v1.6. The new pushbutton utilizes a considerably larger form factor (12mm x 12mm instead of 6mm x 6mm), but it was found that this can be placed on the peripheral board without needing to widen the board, so it should be an effective solution.

One final consideration for RGBSaber v1.6 is the movement to the PIC18F2xK22 series of devices. The PIC18F2221 has served RGBSaber well, but is somewhat older and less powerful than the PIC18F2xK22 counterparts. Given this, and NBitWonder’s rationale for attempting to standardize on a single pin-compatible microcontroller family, RGBSaber v1.6 will utilize a PIC18F2xK22 microcontroller.

Based on yesterday’s explanations for the RGBSaber v1.6 layout, layout was worked on and tweaked for RGBSaber v1.6. I was able to move a large portion of the circuit to the left, freeing up some important routing space for the ground trace to the luxeon LED (previously, it had been dangerously close to the top right mounting hole).

Entry: 015 Time: 3/27/2011 20:29 UTC Version: 1.6 Title: PCB Layout v1.6

Over the past several days, I have been heavily involved in the layout of the RGBSaber v1.6 boards, implementing many of the changes proposed in entry 014. Several parts were added to the NBitWonder Eagle library, including a PLCC-4 LED part and JST connector parts. I sent a draft version of the boards to Ben to get his input on the PCBs. Among other things, he provided suggestions that were valuable for tenting vias on the board and also setting the isolation for the various polygon signal planes to a value other than 0 - helping to mitigate the risk of manufacturing errors.

Entry: 016 Time: 4/15/2011 20:31 UTC Version: 1.6 Title: PCB Layout v1.6 Completion

When layout was completed for the boards, I submitted the boards to FreeDFM (http://freedfm.com/) for an analysis of the boards before sending them off to Advanced Circuits for manufacture. Multiple FreeDFM scans revealed no errors for the peripheral board but 2 issues with the control board. The first were some insufficient trace width violations. In speaking with Ben it was believed that these violations related to the border of the RGBSaber_Control PCB, which is not included in the copper layer of the PCB but could theoretically be picked up for an error nonetheless. Additionally, FreeDFM kept throwing an error for double drill hits - two drill holes that were placed extremely close together. After very careful scrutinization of the board, and talking with Ben, the source of the double drill hits, 2 almost overlapping vias, was discovered. A picture of the overlapping vias is shown in figure 1, below.

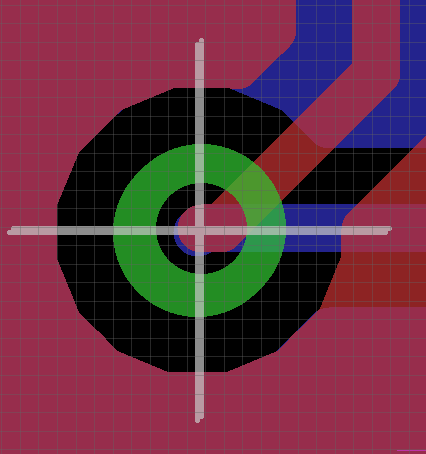
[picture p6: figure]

Fig. 1. Overlapping Via Error

Once the errors were resolved, the designs were sent off to Advanced Circuits for fabrication.

Final images of the RGBSaber control and RGBSaber periph layouts are shown

in figures 2 and 3, below:

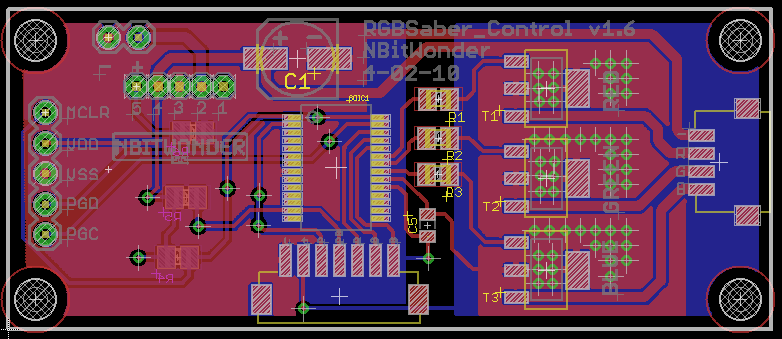
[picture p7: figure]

Fig. 2. RGBSaber_Control v1.6 Layout, Complete

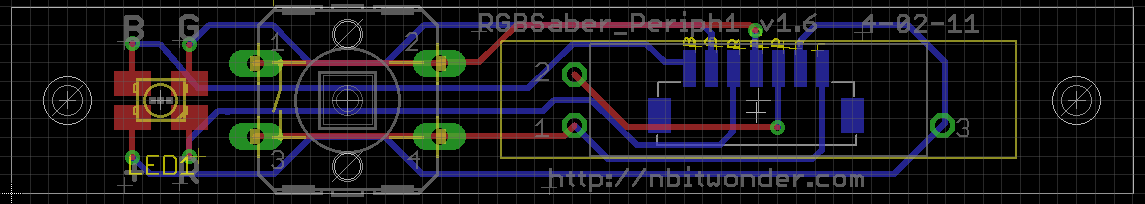
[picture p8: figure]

Fig. 3. RGBSaber_Periph1 v1.6 Layout, Complete

RGBSaber Project Notebook

http://nbitwonder.com 8 ©2011 NBitWonder LLC

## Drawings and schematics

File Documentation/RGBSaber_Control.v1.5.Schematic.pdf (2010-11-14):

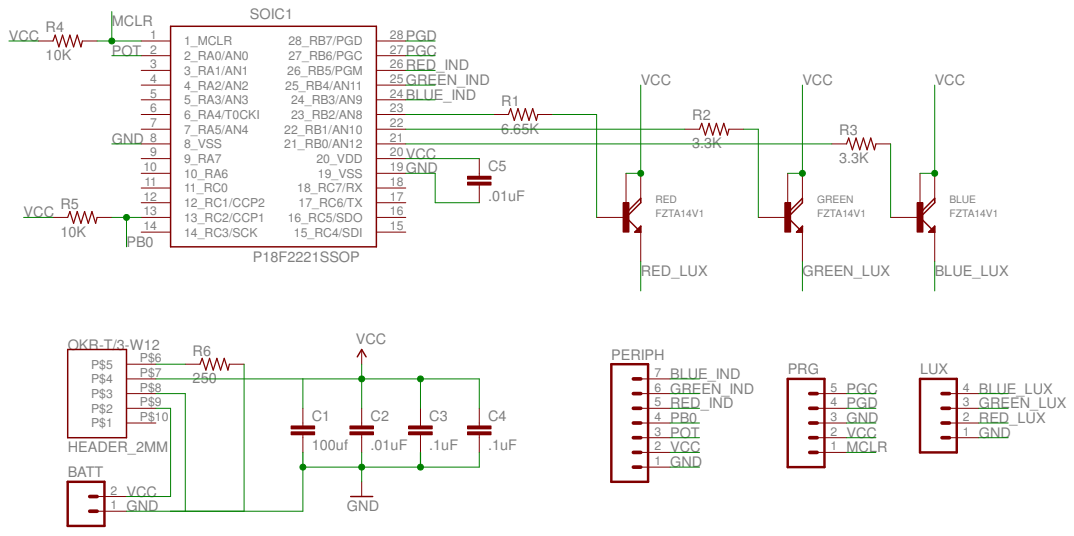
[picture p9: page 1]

10/20/2010 9:49:56 PM C:\Users\George\Documents\eagle\RGB_Lightsaber\rev5\Control\control_rev5.sch (Sheet: 1/1)

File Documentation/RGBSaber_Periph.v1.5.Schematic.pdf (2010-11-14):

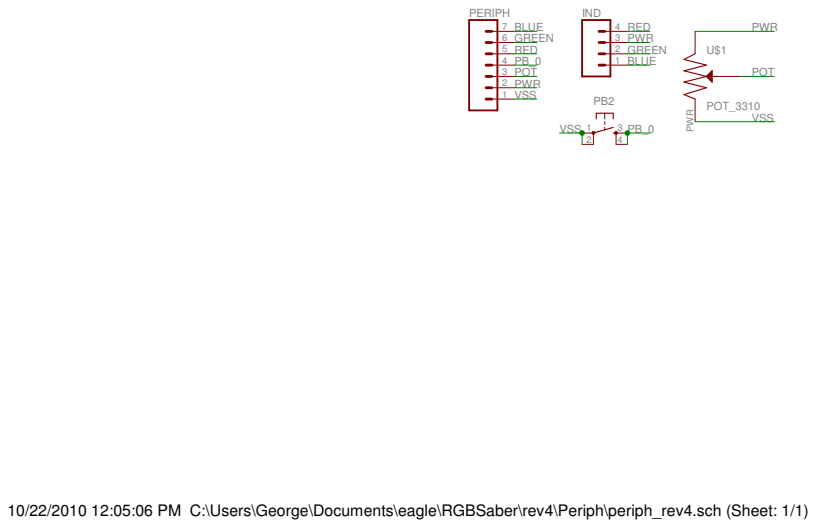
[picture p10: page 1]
POT_3310; IND; PERIPH; PWR; BLUE; GREEN; RED; POT; VSS

10/22/2010 12:05:06 PM C:\Users\George\Documents\eagle\RGBSaber\rev4\Periph\periph_rev4.sch (Sheet: 1/1)

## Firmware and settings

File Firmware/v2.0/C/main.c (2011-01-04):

/*
 * File:   main.c
 * Author: George Hadley
 * Description: main file for RGBSaber firmware v2
 * Created on December 9, 2010, 6:36 PM
 */

#include <p18f2221.h>
#include "aliases.h"
#include "constants.h"
#include "globals.h"
//Global Function Declarations
void T0Interrupt();         //Timer0 interrupt service routine
void Initialize18f2221();   //Microcontroller device initializations

void ToggleColor();         //Used to adjust color state
void ReadColorPort();       //Initiates A/D conversions on active color port
void SoftwarePwm();         //Run Software PWM on color ports

//void IndicateColor();
//void ShiftColor();
//void FlashIndicate();

//void ResetCounter();
//void TimeoutCheck();
//void PowerDown();


void main(void) {
    Initialize18f2221();
    while(1) {
        if(colorPb) {
            ToggleColor();
        }
        ReadColorPort();
        SoftwarePwm();
    }
    return;
}

/*
 * Function: T0Interrupt()
 * Description: Timer0 Overflow Interrupt
 * Notes:
 *   1) IMPORTANT: Clear TMR0IF within the interrupt to prevent immediate
 *          re-entry into the interrupt
 *   2) Switches are momentary contacts to ground, thus a 0 indicates switch
 *          is/was pressed and a 1 indicates switch isn't/wasn't pressed
 * Version: 0.0
 * Last Modified: 12-15-2010
 */
#pragma interruptlow T0Interrupt
void T0Interrupt() {
    INTCONbits.TMR0IF = 0;
    //Button debouncing code: Test for falling edge of color signal
    if(!regColorSelect) {
        //Color selector is currently pressed
        if(colorPbPrev) {
            //Color selector active since last interrupt (switch held down)
            colorPb = 0;
            colorPbPrev = 1;
        }
        //Transition, indicate colorPb press
        colorPb = 1;
        colorPbPrev = 1;
    } else {
        //Color Selector not currently pressed, thus clear flags
        colorPb = 0;
        colorPbPrev = 0;
    }
    return;
}

/*
 * Function: Initialize18f2221()
 * Description: Performs device initializations for the PIC18F2221
 * Notes:
 * Version: 0.0
 * Last Modified: 12-15-2010
 */
void Initialize18f2221() {
    //IO port initializations
    //Initialize portc,2 (color select) and portc,3 (edit select) to inputs
    regColorSelect = 0;
    regEditSelect = 0;
    LATB = 0x18;    //(0001 1000) Turn on red indicator, blade initially off
    TRISB = 0x00;   //(0000 0000) Set portb to be used as outputs
    TRISA = 0xFF;   //(1111 1111) Set porta to be used as inputs

    //ADC Initializations
    ADCON0bits.ADON = 1;    //Activate A/D Converter
    ADCON1 = 0x0E;          //(0000 1110) Configure AN0 as analog input

    //User Variable Initializations
    flashCnt = FLASHVAL;
    msecCnt = SECOND;
    secCnt = MINUTE;
    minCnt = EXPIRE;

    //Interrupt initializations (TMR0 Overflow Interrupt)
    T0CON = 0xC5;   //(1101 0101) Activate timer0 in 8-bit mode, prescale by 64
    INTCONbits.TMR0IE = 1;   //Enable Timer0 Interrupts
    INTCONbits.GIE = 1;      //Enable Global Interrupts

    return;
}

/*
 * Function: ToggleColor()
 * Description: Adjusts the active color flag and indicator in event of
 *      color selector being pushed
 * Notes:
 *   1) Color Indicator LED is, at time of this design, common anode. Therefore,
 *      a given color indicator is turned on by setting it to 0 and turned off
 *      by setting to 1
 * Version: 0.0
 * Last Modified: 12-15-2010
 */
void ToggleColor() {
    if(redFlag) {
        //Activate green flag (green is now active color)
        redFlag = 0;
        greenFlag = 1;
        //Deactivate red indicator, activate green indicator
        regRedIndicate = 1;
        regGreenIndicate = 0;
    } else if(greenFlag) {
        //Activate blue flag (blue is now active color)
        greenFlag = 0;
        blueFlag = 1;
        //Deactivate green indicator, activate blue indicator
        regGreenIndicate = 1;
        regBlueIndicate = 0;
    } else if(blueFlag) {
        //Deactivate all flags (color lock state)
        blueFlag = 0;
        //Deactivate blue indicator (color lock state)
        regBlueIndicate = 1;
    } else {
        //Activate red flag (red is now active color)
        redFlag = 1;
        //Activate red indicator
        regRedIndicate = 0;
    }
    //colorPb was pressed, thus deactivate flag till next press
    colorPb = 0;
    return;
}

/*
 * Function: ReadColorPort()
 * Description: Initiates A/D Conversions on the active color port
 * Notes:
 * Version: 0.0
 * Last Modified: 12-15-2010
 */
void ReadColorPort() {
    ADCON0bits.GO = 1;  //Initiate A/D Conversion on Color Adjuster
    while(ADCON0bits.GO_NOT_DONE) { //Wait for AD conversion to finish
    }
    if(redFlag) {           //If red active, move AD result to previous red
    //    redPrev = ADRESH;
        red = ADRESH;
    } else if(greenFlag) {  //If green active, move AD result to previous green
    //    greenPrev = ADRESH;
        green = ADRESH;
    } else if(blueFlag) {   //If blue active, move AD result to previous blue
    //    bluePrev = ADRESH;
        blue = ADRESH;
    }
    return;
}

/*
 * Function: SoftwarePWM()
 * Description: Performs software PWM on all color ports
 * Notes:
 *   1) The Software PWM algorithm is derived from chapter 21
 *      ("Fun with Trains") of the Basic Stamp App Note found here:
 *      http://www.parallax.com/dl/appnt/stamps/bs1appnotes.pdf
 *   2) regRedPwm, regGreenPwm, and regBluePwm interface to bases of
 *      power transistors, thus setting them to 1 activates the color and
 *      setting them to 0 deactivates the color
 * Version: 0.0
 * Last Modified: 12-15-2010
 */
void SoftwarePwm() {
    redPwm = redPwm + red;
    regRedPwm = STATUSbits.C?1:0;   //If carry bit is set, activate red luxeon
    greenPwm = greenPwm + green;
    regGreenPwm = STATUSbits.C?1:0; //If carry bit is set, activate green luxeon
    bluePwm = bluePwm + blue;
    regBluePwm = STATUSbits.C?1:0;  //If carry bit is set, activate blue luxeon
    return;
}

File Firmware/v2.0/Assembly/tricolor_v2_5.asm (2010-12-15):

;*********************************************************************************************
; File: main.asm
; Description: main assembly file for tricolor lightsaber LED code
; Programmer: George Hadley
; Program History:
;	   Date			Ver					Description
;   10/20/2008 		0.0		Initial program created
;	10/23/2008		0.0		I/O,RTI,ADC initializations developed, button debouncing code created
;								resolved #define error, toggle_color subroutine developed
;	10/25/2008		0.0		Button Toggle code debugged, read_color_port and is_editable routines
;								developed
;	10/26/2008		1.0		is_editable code completed, wrote and debugged pwm output code, removed
;								is_editable from code (for now)
;	11/06/2008		1.0		Worked on tricolor_v1 debug process
;	12/14/2008		1.1		Developed 2-button editability feature
;	12/16/2008		1.2		LED Flash Indicator feature added to indicate color is editable
;	02/19/2009		1.3		Firmware updated to work with common cathode luxeon led
;	03/05/2009		2.0		Began work on lightsaber EEPROM memory access routines
;	03/06/09		2.0		EEPROM Memory access code completed, began work on saber timeout code
;	03/08/09		2.0		tricolor_v2 code completed (not debugged)
;	03/12/09		2.0		configuration bits incorporated into code
;	06/02/09		2.1		Software power_on/power_off code created, editpb button debouncing
;								error corrected
;
; Notes:
;   1) color: A status register containing status flags for color control
;	   Bit	Abbrev. 		Name							Description									Bit Values
;	    0	 editable	Editable Flag				Indicates if currently selected color is	(1:editable, 0:uneditable)
;														editable by color adjuster
;		1	 red_flag	Red Color Select: 			Indicates if red is currently selected 		(1:selected, 0:unselected)
;		2    green_flag	Green Color Select: 		Indicates if green is currently selected 	(1:selected, 0:unselected)
;		3	 blue_flag	Blue Color Select: 			Indicates if blue is currently selected 	(1:selected, 0:unselected)
;		4	 colorpb	Color Pushbutton Flag: 		Indicates if the color pushbutton flag is 
;												   		pressed  								(1:was pressed, 0:was not pressed)
;		5	 prevpb0	Previous Pushbutton Flag 0: Saves previous state of color select
;														pushbutton (used to debounce color 		(1:was pressed, 0:was not pressed)
;														select button)
;		6	 editpb		Color editable pushbutton	Indicates if edit pushbutton is pressed		(1:was pressed, 0:was not pressed)
;		7	 prevpb1	Previous Pushbutton Flag 1:	Saves previous state of edit pushbutton		
;														(used for button debouncing) 			(1:was pressed, 0:was not pressed)
;	2) status0: Status register containing other status flags
;	   Bit	Abbrev.			Name							Description									Bit Values
;		0	flash		Initiate flash bit			Indicates whether to flash indicator or		(1:flash indicator, 0:don't flash)
;														not
;		1	inactive	Lightsaber inactivity		Indicates if no activity has occurred since	(1:inactive, 0:active)
;														previous start loop
;		2	onesec		1-second flag				Indicates 1 second has passed				(1:second passed, 0:second not passed)
;	
;	3) Program I/O pins:
;	   Pin	      Abbrev			Name						Description
;     02(AN0)	color_adjust	Color Adjuster Pin		Color adjuster slider pin
;	  13(RC2)	color_select	Color Selector Pin		Color selecter pushbutton pin
;	  14(RC3)	edit_select		Edit Selector Pin		Color edit select pushbutton
;	  21(RB0)   blue_pwm		Blue PWM Output Pin		PWM output for Blue LEDs
;	  22(RB1)   green_pwm		Green PWM Output Pin	PWM output for Green LEDs
;	  23(RB2)   red_pwm			Red PWM Output Pin		PWM output for Red LEDs
;	  24(RB3)	blue_indicate	Blue LED indicator		Output for blue led status indicator
;	  25(RB4)	green_indicate	Green LED indicator		Output for green led status indicator
;	  26(RB5)	red_indicate	Red LED indicator		Output for red led status indicator
;
;	4) Interrupt Rate: 8.192ms
;
;	5) If there exists a chance that pins have "funky" voltages (diodes, transistors w/o resistors, etc), use latch pins instead of port pins
;
; To-Do List:
;   X) Initialize Interrupts
;	X) Initialize A/D Converter
;	X) Write up button debouncing code for color select button
;	X) Write up color select indicator code based on state of color select button
;	X) Debug color select indicator code
;	X) Write up A/D Converter input code for color adjuster
;	X) Write up PWM output code based on A/D converted color adjuster input
;	X) Develop color edit flag code and integrate into PWM output
;	9) Add auto shutdown feature after certain period of inactivity has passed
;  10) Write up code to save final state of blade before power off and re-enable upon power-up
;   X) Develop code to make indicator light flash when color is editable
;*********************************************************************************************
	#include<p18f2221.inc>
	list p = p18f2221, r = dec
	;set configuration bits
	config wdt=off,lvp=off,osc=intio2,bor=off,cp0=off,cp1=off,cpb=off,cpd=off,wrt0=off,wrt1=off,wrtd=off
	cblock 0	;Variable initializations
		color		  ;color status register (see note 1 in header)
		status0	  	  ;general status register 0 (see note 2 in header)
		msec_cnt	  ;milisecond count register (counts interrupts)
		sec_cnt		  ;second count register (counts interrupts)
	    min_cnt		  ;minute count register (counts interrupts)
		flashcnt	  ;flash count register (counts interrupts)
		red_level1	  ;stores previous red color level
		green_level1	  ;stores previous green color level
		blue_level1	  ;stores previous blue color level
		red_level0	  ;stores current color level of red leds
		green_level0  ;stores current color level of green leds
		blue_level0	  ;stores current color level of blue leds
		red_pwm_acc   ;red pwm accumulator register
		green_pwm_acc ;green pwm accumulator register
		blue_pwm_acc  ;blue pwm accumulator register
	endc
	;color bit definitions
	#define	editable color,0
	#define	red_flag color,1
	#define	green_flag color,2
	#define	blue_flag color,3
	#define	colorpb color,4
	#define	prevpb0 color,5
	#define	editpb	color,6
	#define	prevpb1	color,7

	;status0 bit definitions
	#define flash status0,0
	#define inactive status0,1
	#define onesec status0,2
	
    ;I/O pin definitions
	#define color_adjust porta,0
	#define	blue_pwm latb,0
	#define	green_pwm latb,1
	#define red_pwm latb,2
	#define blue_indicate latb,3
	#define green_indicate latb,4
	#define red_indicate latb,5
	#define color_select portc,2
	#define edit_select portc,3

	;Program constants
	;Memory storage locations for red/green/blue pwm values
	#define	red_loc 0x00
	#define green_loc 0x01
	#define	blue_loc 0x02
	;Timing Constants
	#define second d'122'
	#define	minute d'60'
	#define	expire 1
	;Other Definitions
	#define flashval 0x20			;Flash count value
		
	org 0
	movlw 	b'01111000'	;Initialize 8MHz internal clock
	movwf 	OSCCON			
	bra 	initialize	;skip ahead to start of code (leave space for interrupt code)
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

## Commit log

2010-11-14 Initial repository commit
    [RGBSaber_v1r5_BOM.xlsx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]
2010-11-15 Resolved v1.5 hardware issues, reorganized hardware files
    [control_panel_rev4.brd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]
2010-11-15 Reorganized Hardware files, resolved v1.5 hardware file issues
    [control_panel_rev4.brd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]
2010-12-15 Added initial version of RGBSaber 1.6 hardware, C code firmware v2.0
    [periph_rev4.brd, periph_rev4.sch, rgbsaber_control_v1.6.brd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]
2011-01-04 Added source code, began working on v1.5 documentation using open documentation templates
    [RGBSaber_v1r5_BOM.xlsx]
2011-01-06 Reorganized Hardware section of folder
    [RGBSaber_v1r5_BOM.xlsx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]
2011-04-05 Modified documentation hierarchy, elliminating version-based documentation in favor of a single documentation structure
    [rgbsaber_control_v1.6.brd, rgbsaber_control_v1.6.sch, rgbsaber_periph1_v1.6.brd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]
2011-04-05 Added RGBSaber_Control panel board files, removed autosave files
    [rgbsaber_control_v1.6.GBL, rgbsaber_control_v1.6.GBO, rgbsaber_control_v1.6.GBS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]
2011-04-05 Renamed peripheral board files
    [periph1_v1.0.brd, periph1_v1.0.sch]
2011-04-05 Added RGBSaber_Periph1 panel board files, removed autosave files
    [rgbsaber_periph1_v1.6_panel.brd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]
2011-04-08 Updated RGBSaber Control files, updated Bill of Materials to reflect version 1.6.
    [rgbsaber_control_v1.6.brd, rgbsaber_periph1_v1.6.brd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]
2011-04-26 Added published folder to hardware for easy access to current documentation
2011-10-14 Repository overhaul; LaTeX -> OpenOffice documentation conversion
    [RGBSaber_v1.6_BOM.ods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]
